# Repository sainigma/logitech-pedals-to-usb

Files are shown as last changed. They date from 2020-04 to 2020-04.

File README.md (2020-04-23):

# Logitech Pedals To Usb

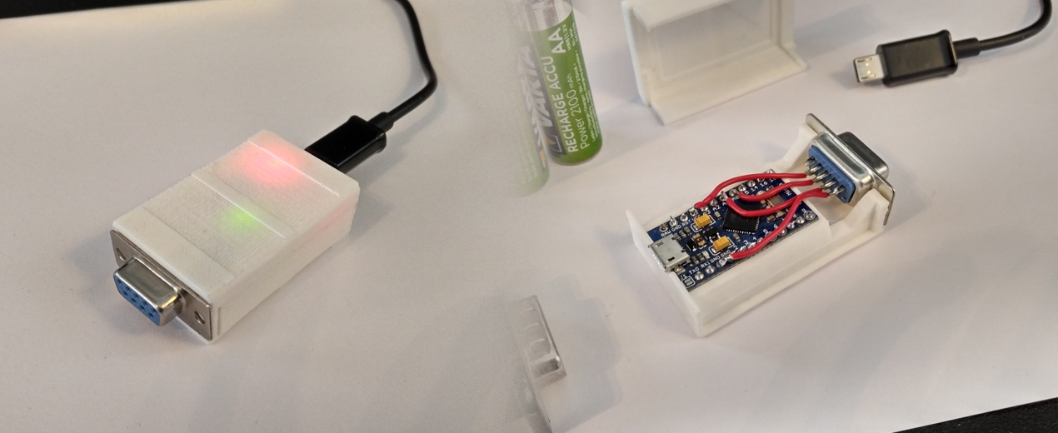
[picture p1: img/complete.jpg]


Complete hardware project for using the Logitech pedals as an independent usb device e.g. as rudders, or as push-to-talk switches (works with Discord).

## Usage

  Connect the pedals to the device and plug it to usb. During startup keep the pedals first at rest and then press them down to change modes. The initialization phase ends after 5 seconds by default.
  
  Modes:
  - Combined accelerator & brake reporting, keep the pedals at rest for the whole phase.
  - Separate axis reporting, keep one of the pedals pressed
  - Digital reporting only, keep both of the pedals pressed

## Requirements

  - Logitech racing wheel (Tested with Momo Racing Wheel, most likely works with other Logitech pedals as well)
  - Arduino with ATmega32u4 (Leonardo, Pro micro etc.)
  - [Arduino Joystick Library](https://github.com/MHeironimus/ArduinoJoystickLibrary)

## Case

  The case is designed for Pro Micro and is toleranced for snap fit. The DB9 socket has to be glued to the wall of the lower case. [The STL files](models/stl/) contain toleranced models, while the [STEP files](models/step) contain models with exact dimensions.

## Wiring

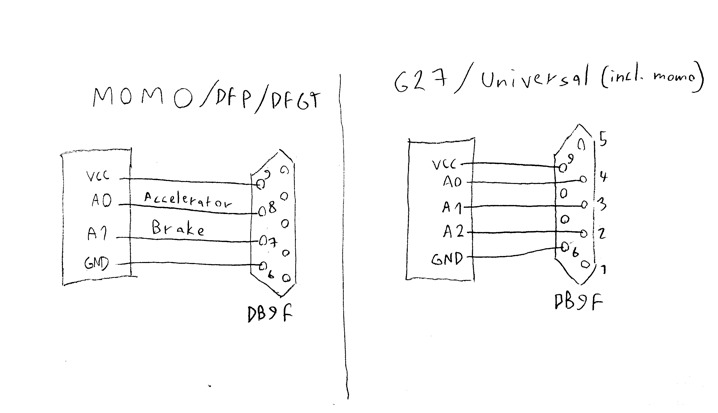
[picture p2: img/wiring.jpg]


  Connect DB9 pin 9 to VCC and pin 6 to GND. For MOMO/DFP/DFGT pots are wired as pairs to 2&7 and 3&8. For G27 only pins 2, 3 and 4 are used for pots.
  
  If you plan to use this for only MOMO, solder pins 7 and 8 to analog inputs for simpler wiring. If you plan to use this with G27 or want a more universal adapter, solder pins 2, 3 and 4 to analog inputs.

  Modify the configuration macros at project file to enable clutch and if axes are mapped wrong.

## Instructions

  1. Clone repo
  2. Install [Arduino Joystick Library](https://github.com/MHeironimus/ArduinoJoystickLibrary)
  3. Modify the configuration macros in LogitechPedalsToUsb.ino to
      - Rearrange input pins
      - Invert axes
      - Enable clutch 
      - Change initialization phase duration
  4. Compile LogitechPedalsToUsb.ino and upload
  5. 3d-print the case and solder the circuit
  6. Glue DB9 socket to the outer wall of the case
  7. Snap the case shut
  8. Enjoy

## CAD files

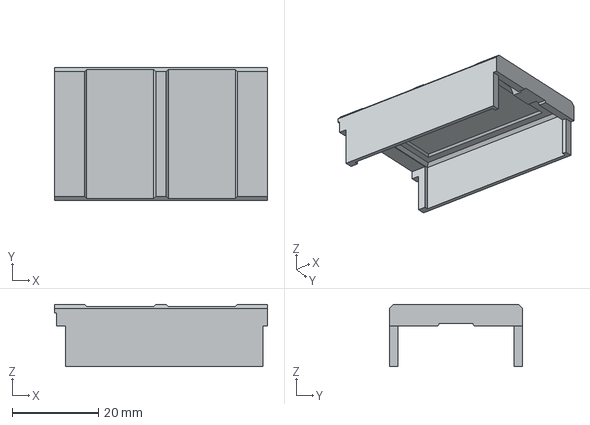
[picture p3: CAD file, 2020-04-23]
models/step/roof.stp
49.5 x 31.0 x 14.5 mm

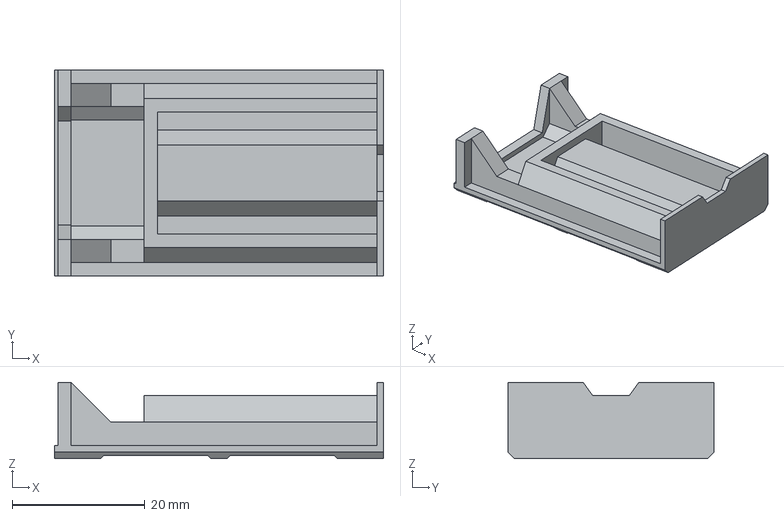
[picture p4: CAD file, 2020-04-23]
models/step/case.stp
49.5 x 31.0 x 11.5 mm

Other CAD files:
models/stl/case.stl
models/stl/roof.stl

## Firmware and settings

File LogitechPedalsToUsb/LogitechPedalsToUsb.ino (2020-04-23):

/*
  USB Adapter for Momo Racing Wheel pedals.

  The pedals connect with a DB9 male. Wire as so:
    -DB9 pin 4 and/or 9 to VCC
    -DB9 pin 3 and/or 8 to THROTTLEPIN
    -DB9 pin 2 and/or 7 to BRAKEPIN
    -DB9 pin 6 to GND

  Created 22 Apr 2020
  Modified 23 Apr 2020
  by Kari Suominen
*/

/* Configuration */
#define THROTTLEPIN A0
#define BRAKEPIN A1
#define CLUTCHPIN A2
#define CLUTCH_ACTIVE false
#define INVERT_THROTTLE false
#define INVERT_BRAKE true
#define INVERT_CLUTCH false
#define JOYSTICK_LOWER_LIMIT 0
#define JOYSTICK_UPPER_LIMIT 1023
#define DELAY_BETWEEN_UPDATES 5
#define INIT_PHASE_SECONDS 5
/* Configuration end */

#define MODE_ANALOG_COMBINED_DIGITAL 0
#define MODE_ANALOG_SEPARATE_DIGITAL 1
#define MODE_DIGITAL 2

#include "src/Pedals/Pedals.h"
#include <Joystick.h>

Joystick_ Joystick;

int timer;
char activeMode;
bool reportCombined;
bool modeInitialized;
Pedals pedals(THROTTLEPIN, BRAKEPIN, CLUTCHPIN, INVERT_THROTTLE, INVERT_BRAKE, INVERT_CLUTCH, JOYSTICK_LOWER_LIMIT, JOYSTICK_UPPER_LIMIT);


void setup() {
  reportCombined = true;
  modeInitialized = false;
  activeMode = -1;
  Joystick.begin();
}

void initializeMode(){
  bool throttleDown = pedals.getThrottleDigital() > 0;
  bool brakeDown = pedals.getBrakeDigital() > 0;
  if( throttleDown && brakeDown ){
    activeMode = MODE_ANALOG_SEPARATE_DIGITAL;
  }else if( throttleDown ){
    activeMode = MODE_DIGITAL;
  }else if( brakeDown ){
    activeMode = MODE_DIGITAL;
  }else{
    activeMode = MODE_ANALOG_COMBINED_DIGITAL;
  }
  modeInitialized = true;
}

void sendAxes(){
  switch( activeMode ){
    case MODE_ANALOG_COMBINED_DIGITAL:
      Joystick.setRzAxis( pedals.getCombined() );
      if( CLUTCH_ACTIVE ) Joystick.setZAxis( pedals.getClutch() );
      break;
    case MODE_ANALOG_SEPARATE_DIGITAL:
      Joystick.setRxAxis( pedals.getThrottle() );
      Joystick.setRyAxis( pedals.getBrake() );
      Joystick.setButton(0, pedals.getThrottleDigital());
      Joystick.setButton(1, pedals.getBrakeDigital());
      if( CLUTCH_ACTIVE ){
        Joystick.setButton(2, pedals.getClutchDigital());
        Joystick.setZAxis( pedals.getClutch() );
      }
      break;
    case MODE_DIGITAL:
      Joystick.setButton(0, pedals.getThrottleDigital());
      Joystick.setButton(1, pedals.getBrakeDigital());
      if( CLUTCH_ACTIVE ) Joystick.setButton(2, pedals.getClutchDigital());
      break;
  }
}

void loop() {
  timer = millis();
  pedals.update();
  if( timer - pedals.getLastUpdate() > DELAY_BETWEEN_UPDATES ){
    if( !modeInitialized && timer > (INIT_PHASE_SECONDS * 1000) ){
      initializeMode();
    }else{
      sendAxes();
    }
  }
}
